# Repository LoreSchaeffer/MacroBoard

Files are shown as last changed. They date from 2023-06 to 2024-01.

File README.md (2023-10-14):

# MacroBoard




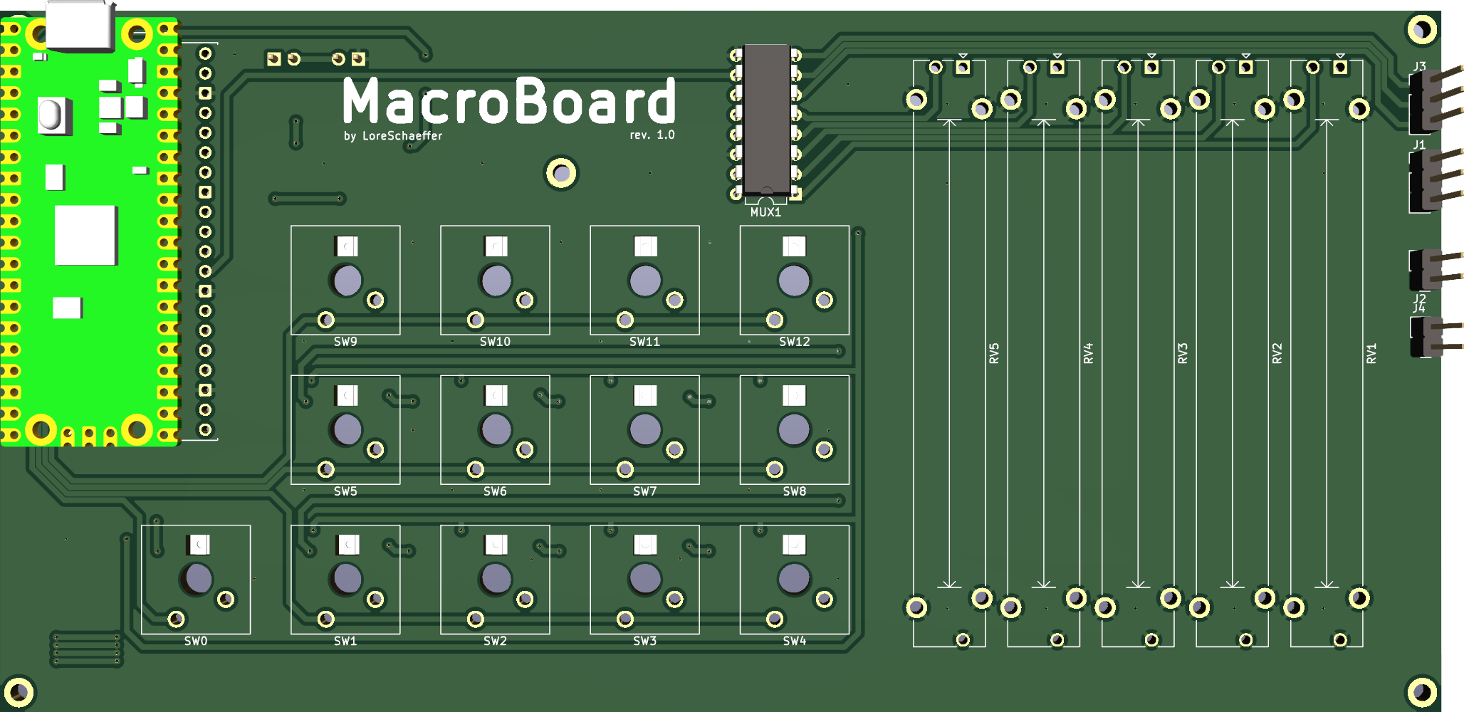
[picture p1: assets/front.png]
Preview


A macro keyboard with programmable keys, RGB leds, programmable slider potentiometers and a lot of expandability through I2C and UART.

### Features
- [x] 13 programmable cherry switch keys
- [x] 13 RGB addressable leds
- [x] 5 slider potentiometers
- [x] WiFi and Bluetooth connectivity
- [x] Battery input (5V)
- [x] 5V and 3.3V power outputs
- [x] I2C expansion port
- [x] UART expansion port
- [x] LED data expansion port
- [ ] 3D printable case
- [ ] Firmware
- [ ] Software

## Contributing
To contribute to this repository just fork this repository make your changes or add your code and make a pull request.

## License
MacroBoard is released under the MIT license. You can find a copy [here](https://github.com/LoreSchaeffer/MacroBoard/blob/master/LICENSE)

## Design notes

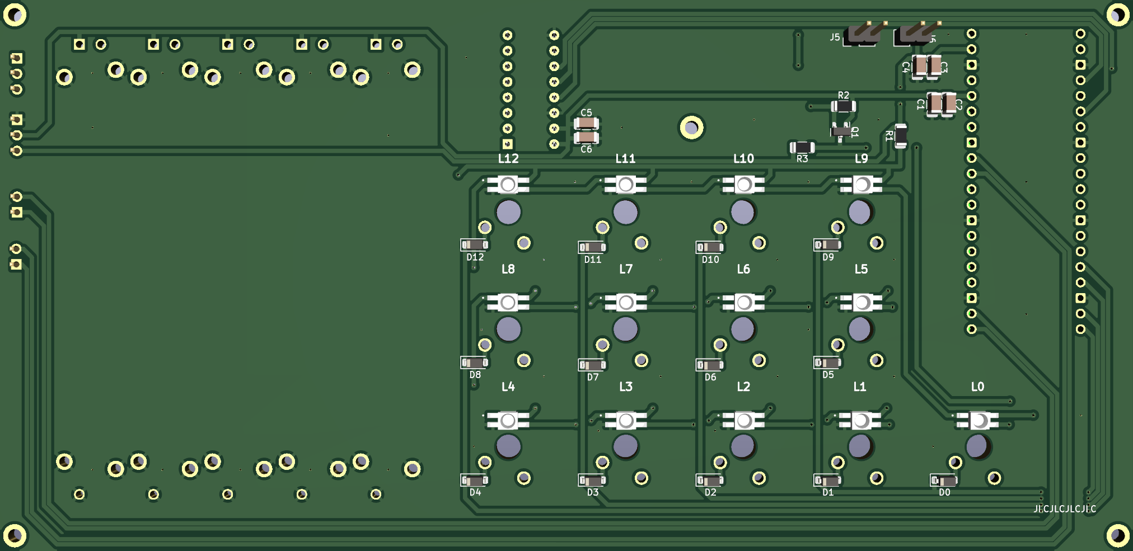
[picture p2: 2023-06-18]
assets/back.png

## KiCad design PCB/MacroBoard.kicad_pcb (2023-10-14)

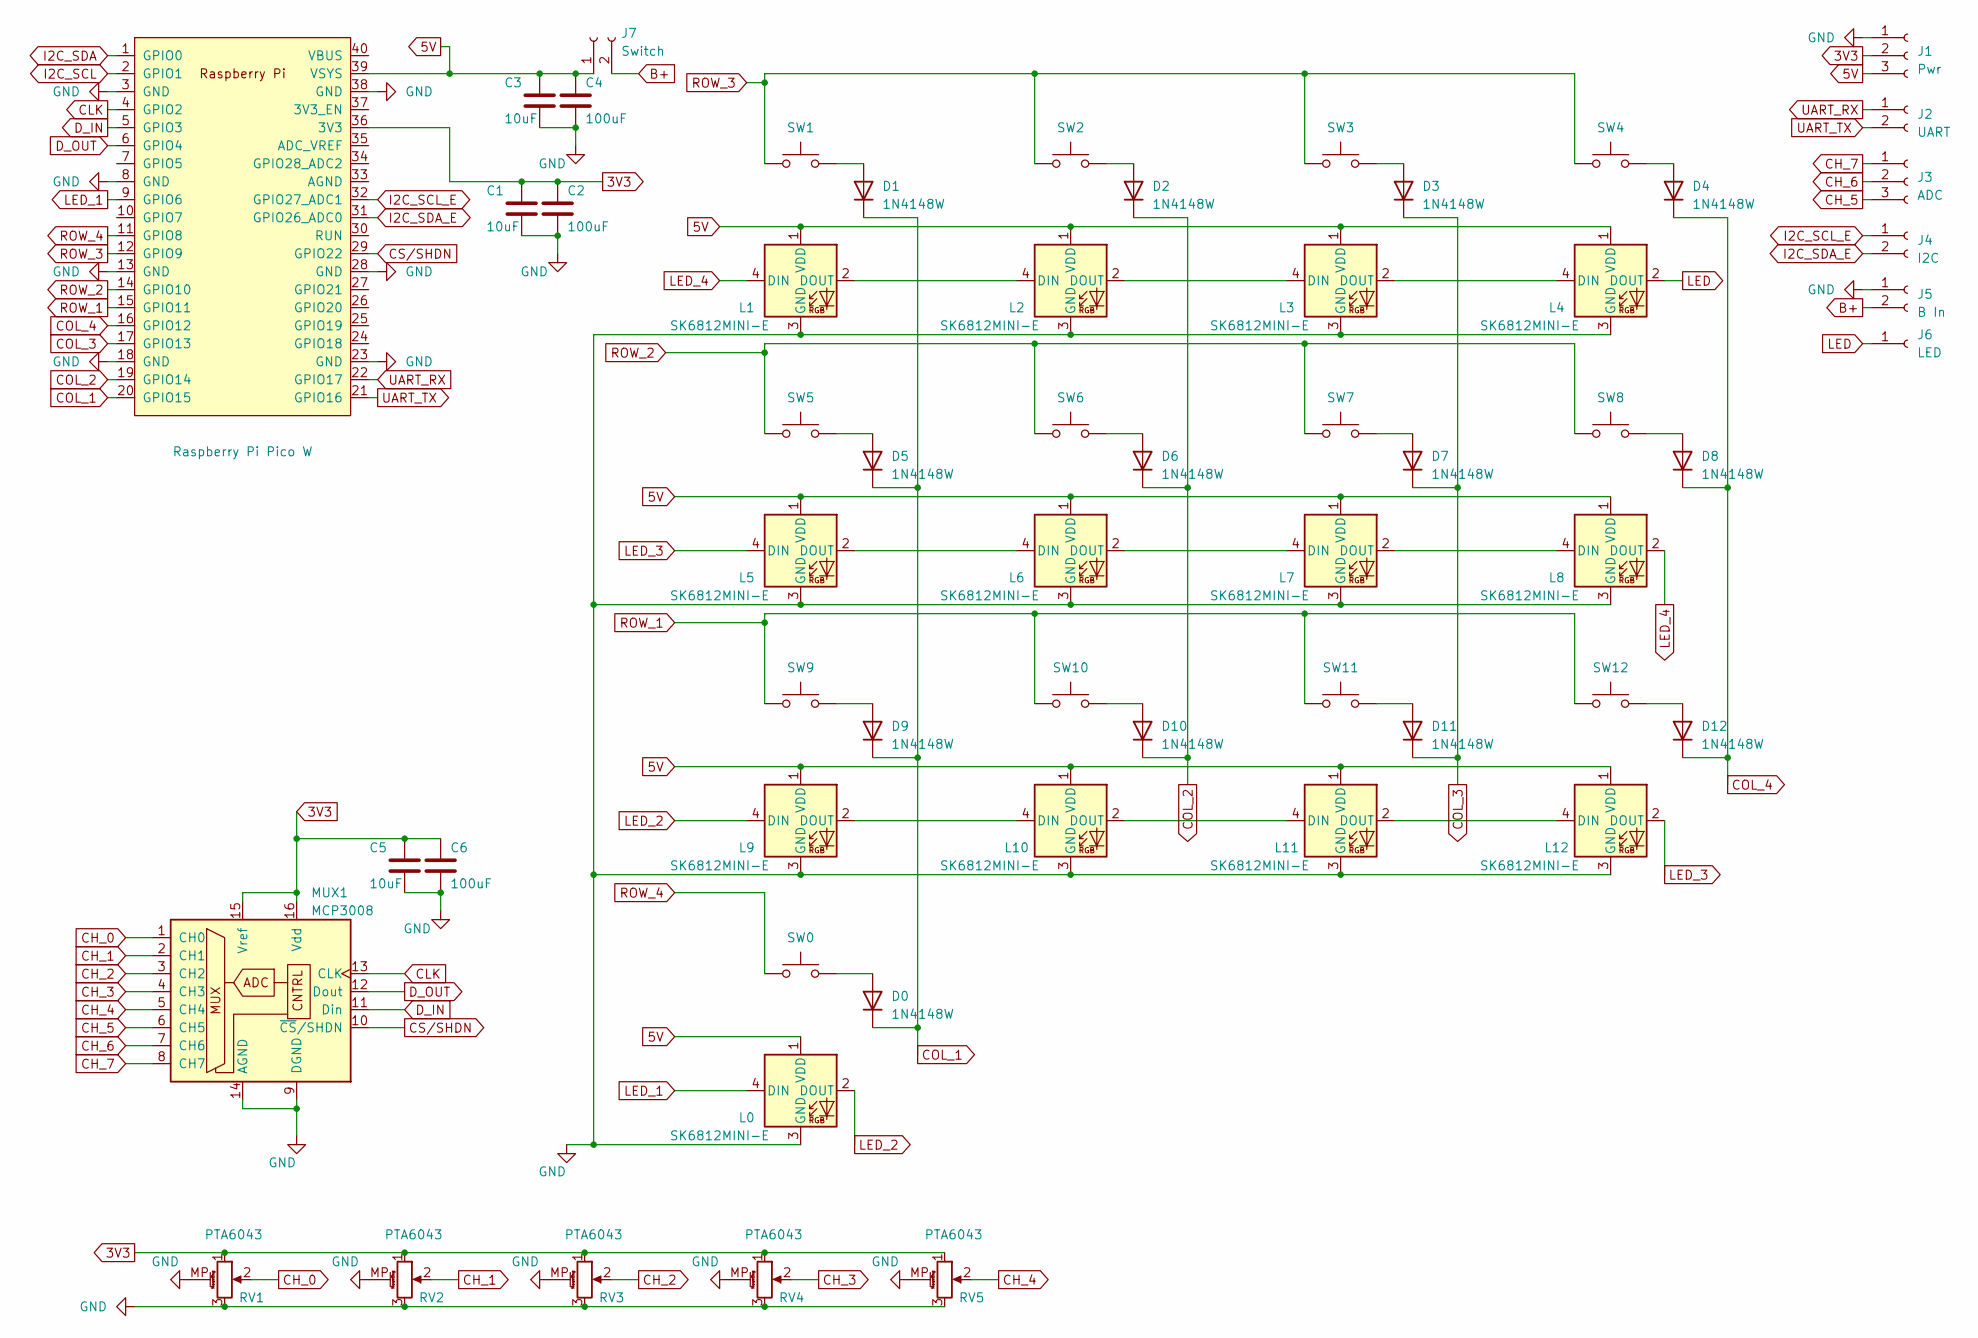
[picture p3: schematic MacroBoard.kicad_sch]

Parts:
C1, C3, C5: 10uF; C_1206_3216Metric
C2, C4, C6: 100uF; C_1206_3216Metric
D0, D1, D2, D3, D4, D5, D6, D7, D8, D9, D10, D11, D12: 1N4148W; D_SOD-123
J1: Pwr; PinHeader_1x03_P2.54mm_Vertical
J2: UART; PinHeader_1x02_P2.54mm_Vertical
J3: ADC; PinHeader_1x03_P2.54mm_Vertical
J4: I2C; PinHeader_1x02_P2.54mm_Vertical
J5: B In; PinHeader_1x02_P2.54mm_Vertical
J6: LED; Pin_D0.7mm_L6.5mm_W1.8mm_FlatFork
J7: Switch; PinHeader_1x02_P2.54mm_Vertical
L0, L1, L2, L3, L4, L5, L6, L7, L8, L9, L10, L11, L12: SK6812MINI-E; SK6812MINIE
MUX1: MCP3008; DIP-16_W7.62mm
RPPW1: Raspberry Pi Pico W; MODULE_SC0918
RV1, RV2, RV3, RV4, RV5: PTA6043; Potentiometer_Bourns_PTA6043_Single_Slide
SW0, SW1, SW2, SW3, SW4, SW5, SW6, SW7, SW8, SW9, SW10, SW11, SW12: SW_Push; SW_Cherry_MX_1.00u_Plate

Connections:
3V3: C1.1, C2.1, C5.1, C6.1, J1.2, MUX1.15 (Vref), MUX1.16 (Vdd), RPPW1.36 (3V3), RV1.1, RV2.1, RV3.1, RV4.1, RV5.1
5V: C3.1, C4.1, J1.3, J7.1, L0.1 (VDD), L1.1 (VDD), L2.1 (VDD), L3.1 (VDD), L4.1 (VDD), L5.1 (VDD), L6.1 (VDD), L7.1 (VDD), L8.1 (VDD), L9.1 (VDD), L10.1 (VDD), L11.1 (VDD), L12.1 (VDD), RPPW1.39 (VSYS)
B+: J5.2, J7.2
CH_0: MUX1.1 (CH0), RV1.2
CH_1: MUX1.2 (CH1), RV2.2
CH_2: MUX1.3 (CH2), RV3.2
CH_3: MUX1.4 (CH3), RV4.2
CH_4: MUX1.5 (CH4), RV5.2
CH_5: J3.3, MUX1.6 (CH5)
CH_6: J3.2, MUX1.7 (CH6)
CH_7: J3.1, MUX1.8 (CH7)
CLK: MUX1.13 (CLK), RPPW1.4 (GPIO2)
COL_1: D0.1 (K), D1.1 (K), D5.1 (K), D9.1 (K), RPPW1.20 (GPIO15)
COL_2: D2.1 (K), D6.1 (K), D10.1 (K), RPPW1.19 (GPIO14)
COL_3: D3.1 (K), D7.1 (K), D11.1 (K), RPPW1.17 (GPIO13)
COL_4: D4.1 (K), D8.1 (K), D12.1 (K), RPPW1.16 (GPIO12)
CS/SHDN: MUX1.10 (~CS/SHDN), RPPW1.29 (GPIO22)
D_IN: MUX1.11 (Din), RPPW1.5 (GPIO3)
D_OUT: MUX1.12 (Dout), RPPW1.6 (GPIO4)
GND: C1.2, C2.2, C3.2, C4.2, C5.2, C6.2, J1.1, J5.1, L0.3 (GND), L1.3 (GND), L2.3 (GND), L3.3 (GND), L4.3 (GND), L5.3 (GND), L6.3 (GND), L7.3 (GND), L8.3 (GND), L9.3 (GND), L10.3 (GND), L11.3 (GND), L12.3 (GND), MUX1.9 (DGND), MUX1.14 (AGND), RPPW1.3 (GND), RPPW1.8 (GND), RPPW1.13 (GND), RPPW1.18 (GND), RPPW1.23 (GND), RPPW1.28 (GND), RPPW1.38 (GND), RV1.3, RV1.MP (MountPin), RV2.3, RV2.MP (MountPin), RV3.3, RV3.MP (MountPin), RV4.3, RV4.MP (MountPin), RV5.3, RV5.MP (MountPin)
I2C_SCL: RPPW1.2 (GPIO1)
I2C_SCL_E: J4.1, RPPW1.32 (GPIO27_ADC1)
I2C_SDA: RPPW1.1 (GPIO0)
I2C_SDA_E: J4.2, RPPW1.31 (GPIO26_ADC0)
LED: J6.1, L4.2 (DOUT)
LED_1: L0.4 (DIN), RPPW1.9 (GPIO6)
LED_2: L0.2 (DOUT), L9.4 (DIN)
LED_3: L5.4 (DIN), L12.2 (DOUT)
LED_4: L1.4 (DIN), L8.2 (DOUT)
unnamed: D0.2 (A), SW0.2
unnamed: D1.2 (A), SW1.2
unnamed: D2.2 (A), SW2.2
unnamed: D3.2 (A), SW3.2
unnamed: D4.2 (A), SW4.2
unnamed: D5.2 (A), SW5.2
unnamed: D6.2 (A), SW6.2
unnamed: D7.2 (A), SW7.2
unnamed: D8.2 (A), SW8.2
unnamed: D9.2 (A), SW9.2
unnamed: D10.2 (A), SW10.2
unnamed: D11.2 (A), SW11.2
unnamed: D12.2 (A), SW12.2
unnamed: L1.2 (DOUT), L2.4 (DIN)
unnamed: L2.2 (DOUT), L3.4 (DIN)
unnamed: L3.2 (DOUT), L4.4 (DIN)
unnamed: L5.2 (DOUT), L6.4 (DIN)
unnamed: L6.2 (DOUT), L7.4 (DIN)
unnamed: L7.2 (DOUT), L8.4 (DIN)
unnamed: L9.2 (DOUT), L10.4 (DIN)
unnamed: L10.2 (DOUT), L11.4 (DIN)
unnamed: L11.2 (DOUT), L12.4 (DIN)
ROW_1: RPPW1.15 (GPIO11), SW9.1, SW10.1, SW11.1, SW12.1
ROW_2: RPPW1.14 (GPIO10), SW5.1, SW6.1, SW7.1, SW8.1
ROW_3: RPPW1.12 (GPIO9), SW1.1, SW2.1, SW3.1, SW4.1
ROW_4: RPPW1.11 (GPIO8), SW0.1
UART_RX: J2.1, RPPW1.22 (GPIO17)
UART_TX: J2.2, RPPW1.21 (GPIO16)

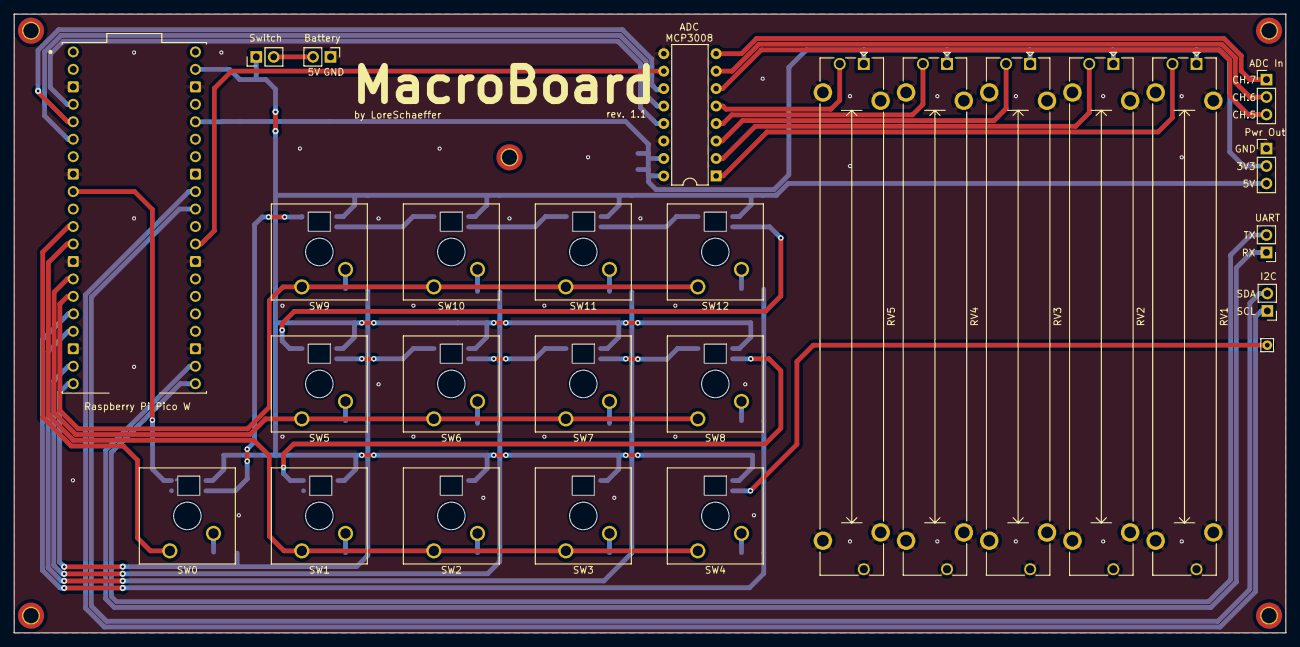
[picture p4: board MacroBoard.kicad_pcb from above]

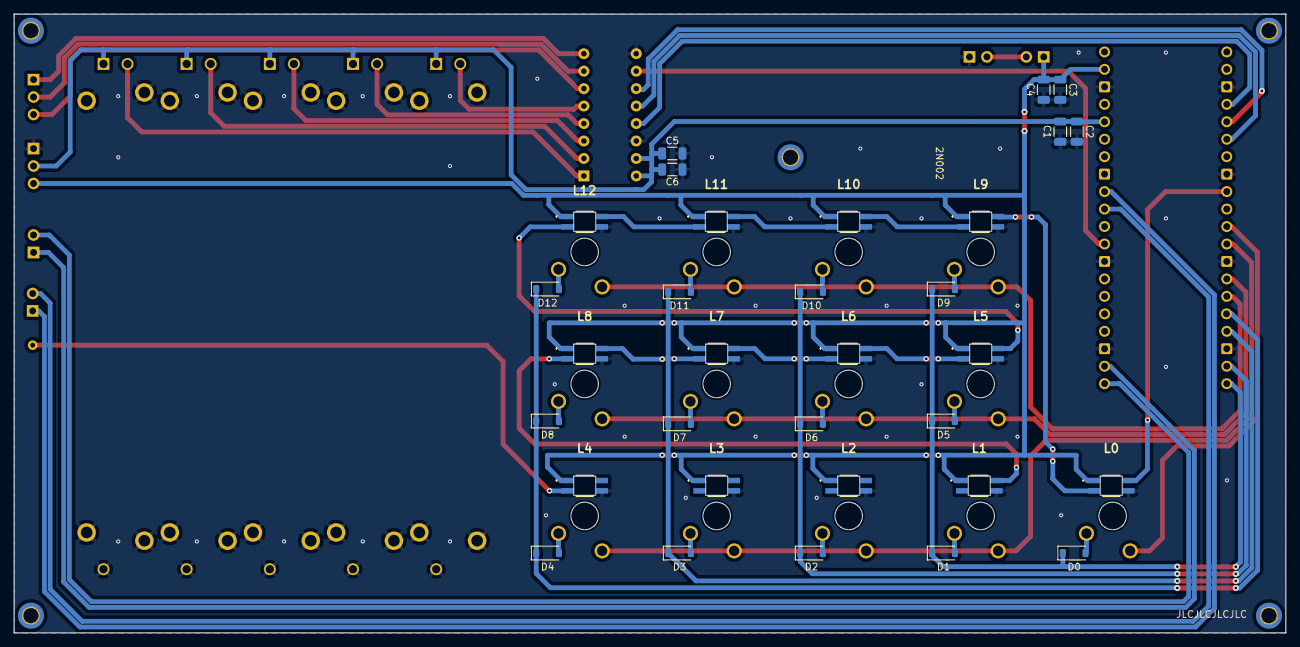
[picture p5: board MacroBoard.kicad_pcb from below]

Board: 2 copper layers, 185.0 x 90.0 mm, 59 parts (32 on the bottom side), 55 nets.

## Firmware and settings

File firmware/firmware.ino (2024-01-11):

#include "kpd.h"
#include "leds.h"
#include "adc.h"
#include "pico/stdlib.h"
#include <Keypad.h>

#define SCK_PIN 2
#define MOSI_PIN 3
#define MISO_PIN 4
#define CS_PIN 22

#define LED_PIN 6
#define NUM_PIXELS 13

const byte KP_ROWS = 4;
const byte KP_COLS = 4;
const char KP_KEYMAP[KP_ROWS][KP_COLS] = {{'0', '1', '2', '3'},
                                          {'4', '5', '6', '7'},
                                          {'8', '9', 'A', 'B'},
                                          {'C', 'D', 'E', 'F'}};
byte KP_ROW_PINS[KP_ROWS] = {11, 10, 9, 8};
byte KP_COL_PINS[KP_COLS] = {15, 14, 13, 12};

Leds leds(LED_PIN, NUM_PIXELS);
KPD keypad(KP_ROWS, KP_COLS, makeKeymap(KP_KEYMAP), KP_ROW_PINS, KP_COL_PINS, 25);
ADC adc(SCK_PIN, MOSI_PIN, MISO_PIN, CS_PIN, false, false, false);

void setup() {
  Serial.begin(11520);
  keypad.setup();
  adc.setup();
  leds.setup();
}

void setup1() {}

void loop() {
  keypadRoutine();
  sliderRoutine();
  ledRoutine();
}

void loop1() {}

long ledRoutineDelay = 20;
long ledRoutineLast = 0;
void ledRoutine() {
  if (ledRoutineLast + ledRoutineDelay < millis()) {
    ledRoutineLast = millis();
    leds.update();
  }
}

long keypadRoutineDelay = 1;
long keypadRoutineLast = 0;
void keypadRoutine() {
  if (keypadRoutineLast + keypadRoutineDelay < millis()) {
    keypadRoutineLast = millis();
    keypad.update();
  }
}

long sliderRoutineDelay = 10;
long sliderRoutineLast = 0;
void sliderRoutine() {
  if (sliderRoutineLast + sliderRoutineDelay < millis()) {
    sliderRoutineLast = millis();
    adc.update();
  }
}

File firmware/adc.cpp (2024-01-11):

#include "adc.h"

#include <Adafruit_MCP3008.h>

#define WINDOW_SIZE 75

ADC::ADC(uint8_t sck, uint8_t mosi, uint8_t miso, uint8_t cs, boolean c5,
         boolean c6, boolean c7)
    : adc(), sck(sck), mosi(mosi), miso(miso), cs(cs), c5(c5), c6(c6), c7(c7) {}

void ADC::setup() {
  adc.begin(sck, mosi, miso, cs);

  values = new float *[8];
  lastValues = new float[8];

  for (int i = 0; i < 8; i++) {
    values[i] = new float[WINDOW_SIZE];
    for (int j = 0; j < WINDOW_SIZE; j++) {
      values[i][j] = (i <= 4 || c5 && i == 5 || c6 && i == 6 || c7 && i == 7)
                         ? (float)adc.readADC(i)
                         : 0;
    }

    lastValues[i] = values[i][0];
  }
}

void ADC::update() {
  for (int c = 0; c < 8; c++) {
    if (!c5 && c == 5)
      continue;
    if (!c6 && c == 6)
      continue;
    if (!c7 && c == 7)
      continue;

    float oldValue = values[c][WINDOW_SIZE - 1];
    float newValue = adc.readADC(c);

    for (int i = WINDOW_SIZE - 1; i > 0; i--) {
      values[c][i] = values[c][i - 1];
    }

    values[c][0] = newValue;

    float valuePercentage = toPercentage(values[c][0]);
    float oldValuePercentage = toPercentage(oldValue);

    if (abs(lastValues[c] - valuePercentage) >= 0.01) {
      Serial.print("Channel ");
      Serial.print(c);
      Serial.print(": ");
      Serial.print(String(oldValuePercentage, 2));
      Serial.print(" -> ");
      Serial.println(String(valuePercentage, 2));

      lastValues[c] = valuePercentage;
    }
  }
}

float ADC::toPercentage(float value) { return value / 1023; }

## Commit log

2023-06-15 Increased power tracks width
    [MacroBoard.kicad_pcb]
2023-06-15 New LED Footprint, new routings
    [MacroBoard.kicad_pcb, MacroBoard.kicad_sch]
2023-06-15 Fixed some routing issues, changed some tracks to reduce interference, added silkscreen
    [MacroBoard.kicad_pcb]
2023-06-18 Updated PCB, increased tracks and vias size, added level converter
    [MacroBoard.kicad_pcb, MacroBoard.kicad_sch]
2023-06-18 Added silkscreen
    [MacroBoard.kicad_pcb]
2023-10-14 Revision 1.1 (Firmware WIP)
    [MacroBoard.kicad_pcb, MacroBoard.kicad_sch]
2024-01-11 ADC working (to refine)
